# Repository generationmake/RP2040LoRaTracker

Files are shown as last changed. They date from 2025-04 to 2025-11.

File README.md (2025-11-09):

# RP2040LoRaTracker
Tracker with a Raspberry Pi RP2040, an AI-Thinker Ra-01 LoRa Module and an u-Blox GNSS receiver

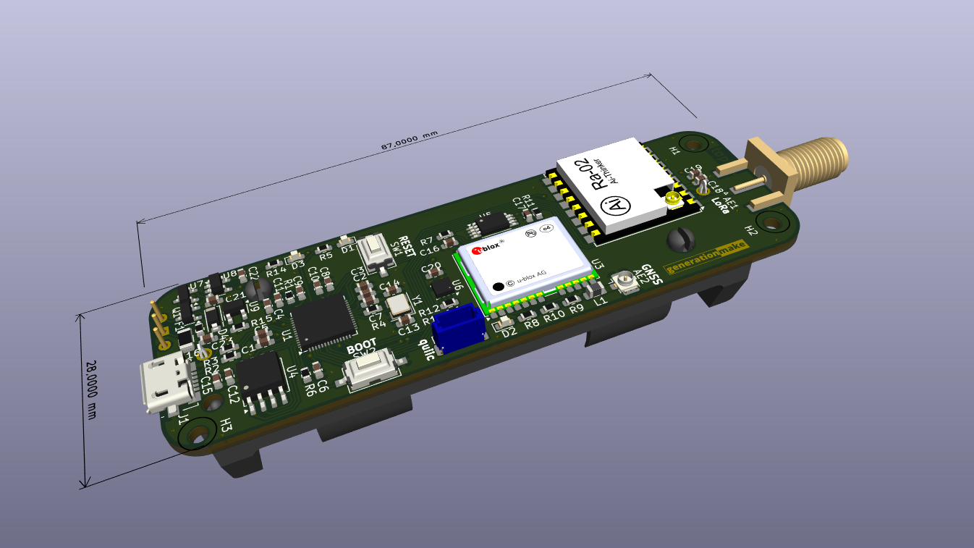
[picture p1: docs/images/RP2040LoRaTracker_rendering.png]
RP2040LoRaTracker rendering


## Firmware
* [ArduinoLoRaAPRSTracker](https://github.com/generationmake/ArduinoLoRaAPRSTracker): This is the default firmware for this board. It enables all basic functions as a ham radio LoRaAPRSTracker

## Antennas

### LoRa antenna (AE1)

SMA connector, 50 Ohm, for 433 MHz LoRa antenna.

### GNSS antenna (AE2)

U.FL connector, 50 Ohm, for GNSS antenna.

## Pinout

### USB (J1)

Micro-USB connector, connected to the RP2040 ant to charge the battery.

### I2C (J2)

compatible to the Sparkfun qwiic standard (https://www.sparkfun.com/qwiic). JST SH 1mm 4-pin.

| pin number | signal |
|:---:|:---:|
| 1 | GND |
| 2 | +3V3 |
| 3 | I2C_SDA |
| 4 | I2C_SCL |

## Switches

### Reset (SW1)

push button to reset RP2040.

### Boot (SW2)

push button to set RP2040 to boot mode.

### on/off (SW3)

sliding switch to power board from battery.

## enclosure

There exists a 3D printable enclosure to encapsulate the PCB.

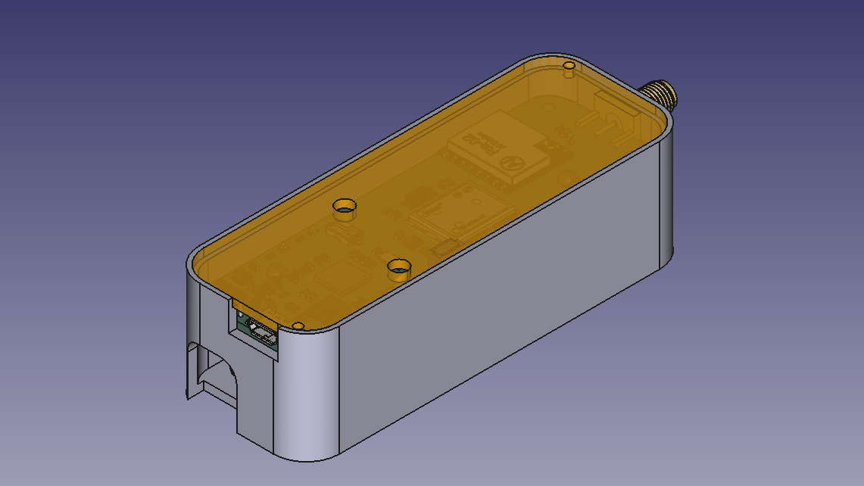
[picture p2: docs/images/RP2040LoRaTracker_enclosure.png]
RP2040LoRaTracker enclosure


## PCB

### Top

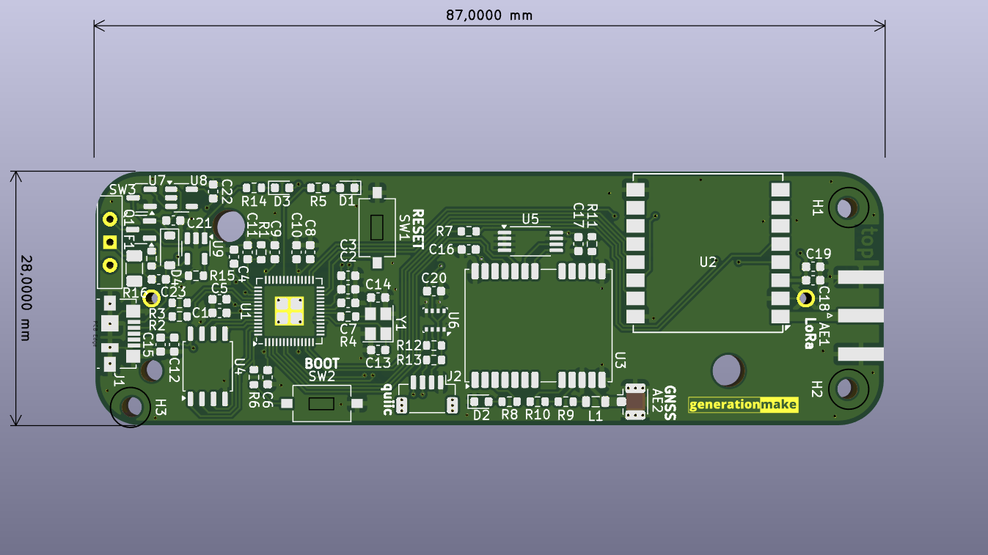
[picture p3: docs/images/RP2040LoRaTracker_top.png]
RP2040LoRaTracker PCB top


### Bottom

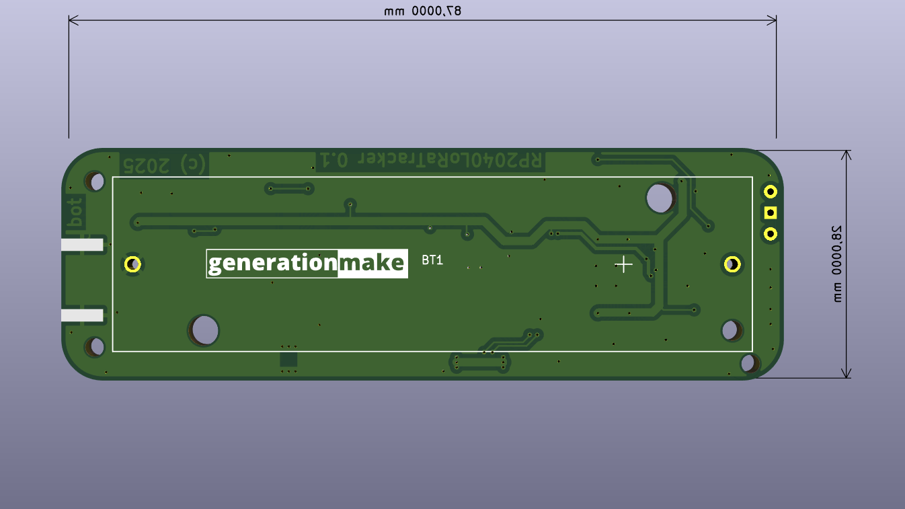
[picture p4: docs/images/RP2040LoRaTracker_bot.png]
RP2040LoRaTracker PCB bot


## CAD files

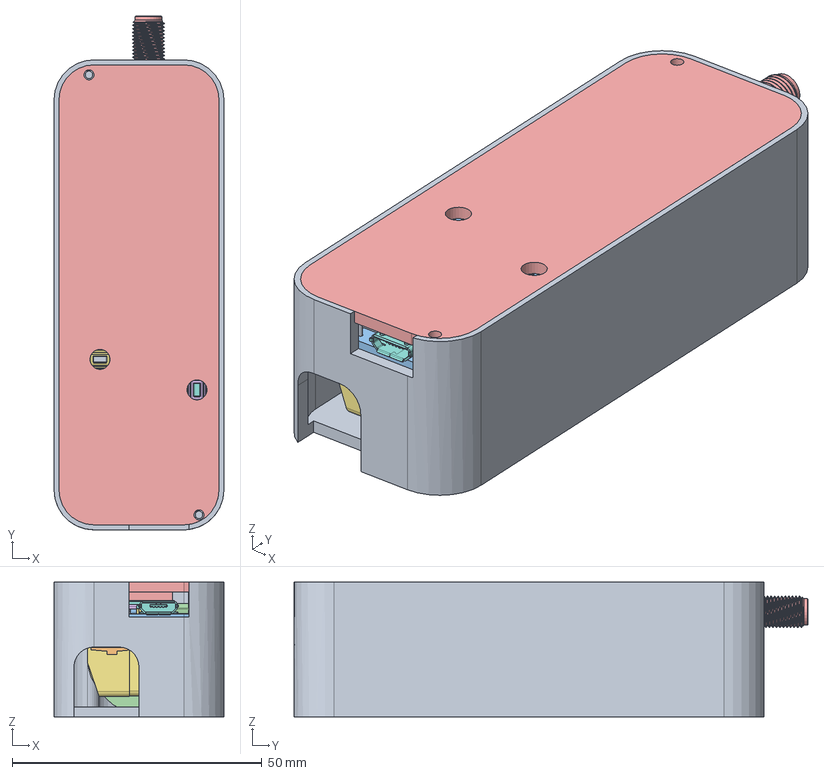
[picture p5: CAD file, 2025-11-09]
freecad_source/enclosure.FCStd
34.0 x 102.7 x 27.0 mm
bot
LED_0603_1608Metric
R_0603_1608Metric
R_0603_1608Metric002
NEO (STEP-AP214)_B
NEO (STEP-AP214)_B001
NEO (STEP-AP214)_B002
NEO (STEP-AP214)_B003
NEO (STEP-AP214)_B004
NEO (STEP-AP214)_B005
NEO (STEP-AP214)_B006
NEO (STEP-AP214)_B007
NEO (STEP-AP214)_B008
NEO (STEP-AP214)_B009
NEO (STEP-AP214)_B010
NEO (STEP-AP214)_B011
NEO (STEP-AP214)_B012
NEO (STEP-AP214)_B013
NEO (STEP-AP214)_B014
NEO (STEP-AP214)_B015
NEO (STEP-AP214)_B016
NEO (STEP-AP214)_B017
NEO (STEP-AP214)_B018
NEO (STEP-AP214)_B019
NEO (STEP-AP214)_B020
NEO (STEP-AP214)_B021
NEO (STEP-AP214)_B022
NEO (STEP-AP214)_B023
NEO (STEP-AP214)_B024
NEO (STEP-AP214)_B025
NEO (STEP-AP214)_B026
NEO (STEP-AP214)_B027
NEO (STEP-AP214)_B028
NEO (STEP-AP214)_B029
NEO (STEP-AP214)_B030
NEO (STEP-AP214)_B031
NEO (STEP-AP214)_B032
L_0805_2012Metric
C_0603_1608Metric
R_0603_1608Metric004
C_0603_1608Metric002
C_0603_1608Metric004
C_0603_1608Metric006
R_0603_1608Metric006
R_0603_1608Metric008
SOT_23
SOT_23_5
C_0603_1608Metric008
Fuse_1206_3216Metric
root
root001
root002
root003
root004
root005
root006
root007
root008
root009
root010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

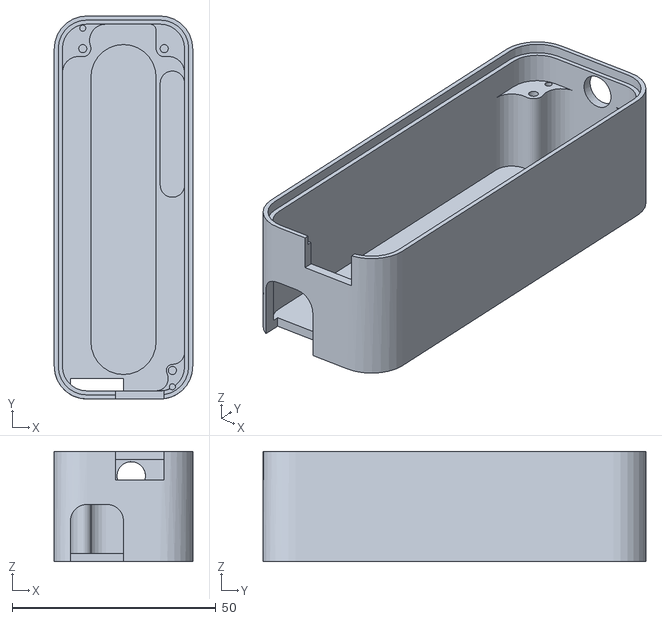
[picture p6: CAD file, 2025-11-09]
production_data/enclosure-bot.stl
34.0 x 94.0 x 27.0

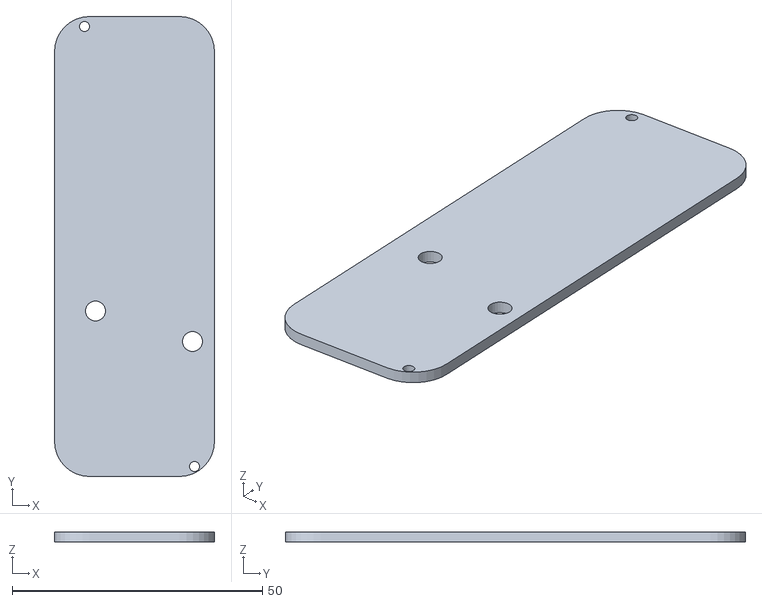
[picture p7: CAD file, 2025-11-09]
production_data/enclosure-top.stl
32.0 x 92.0 x 2.00

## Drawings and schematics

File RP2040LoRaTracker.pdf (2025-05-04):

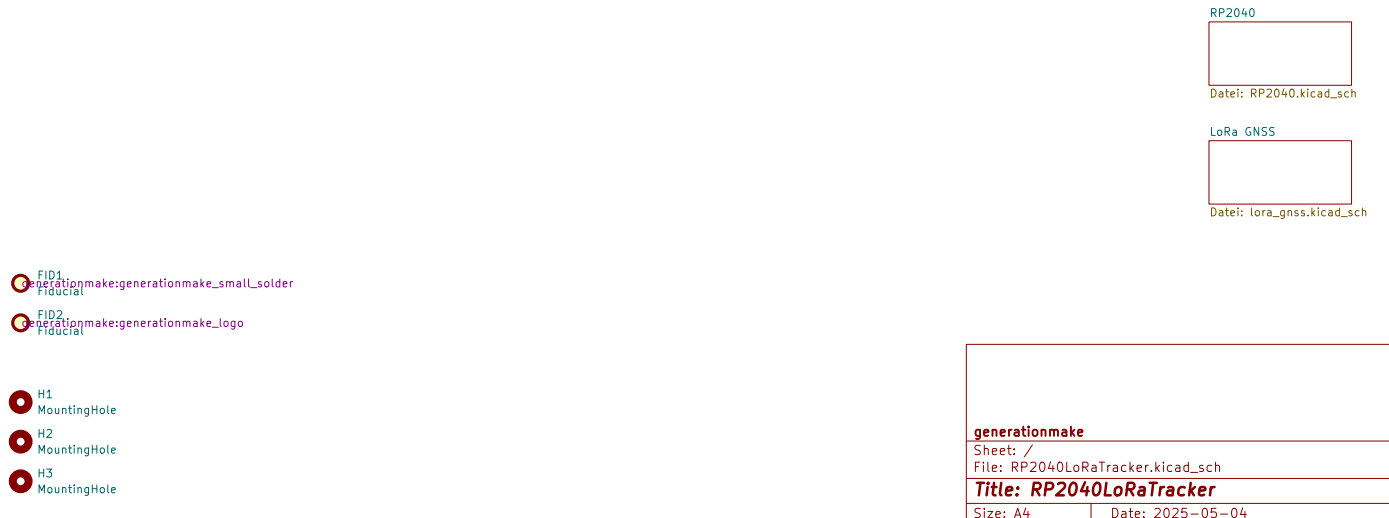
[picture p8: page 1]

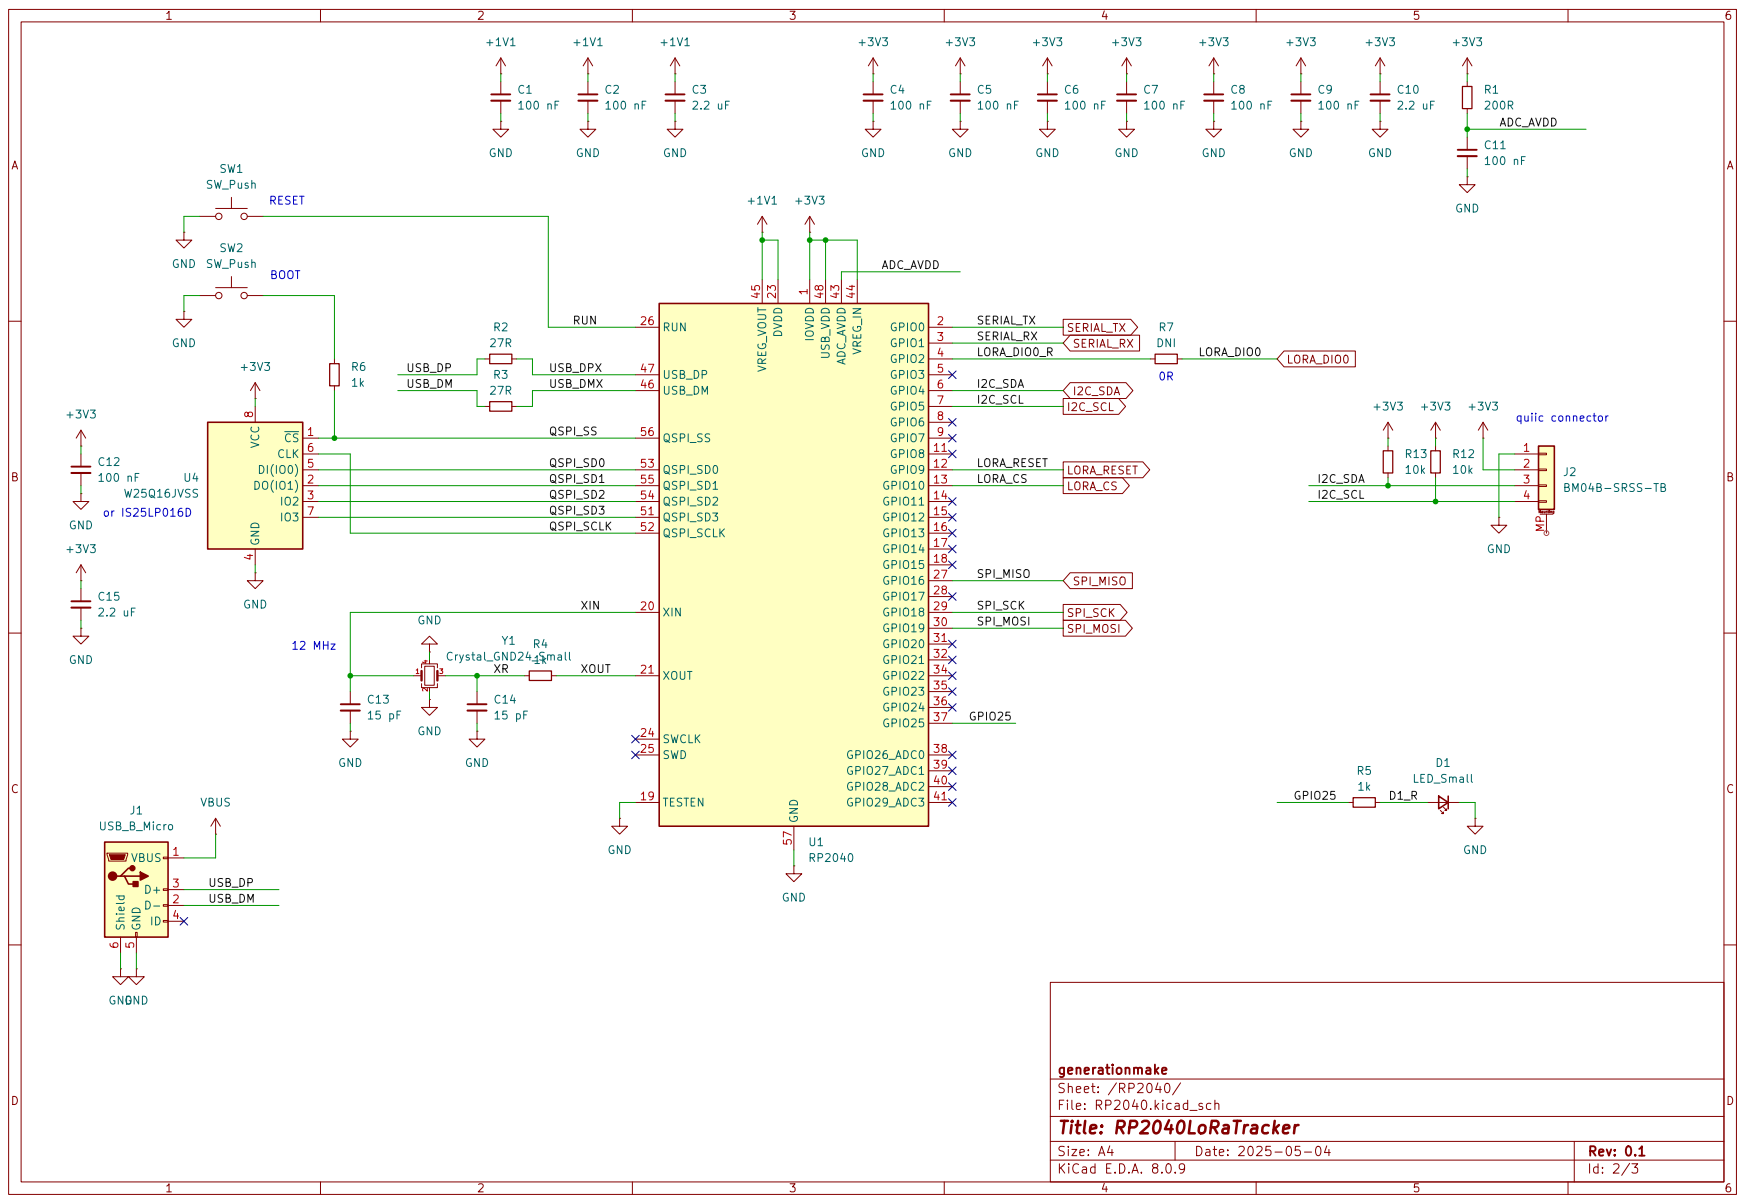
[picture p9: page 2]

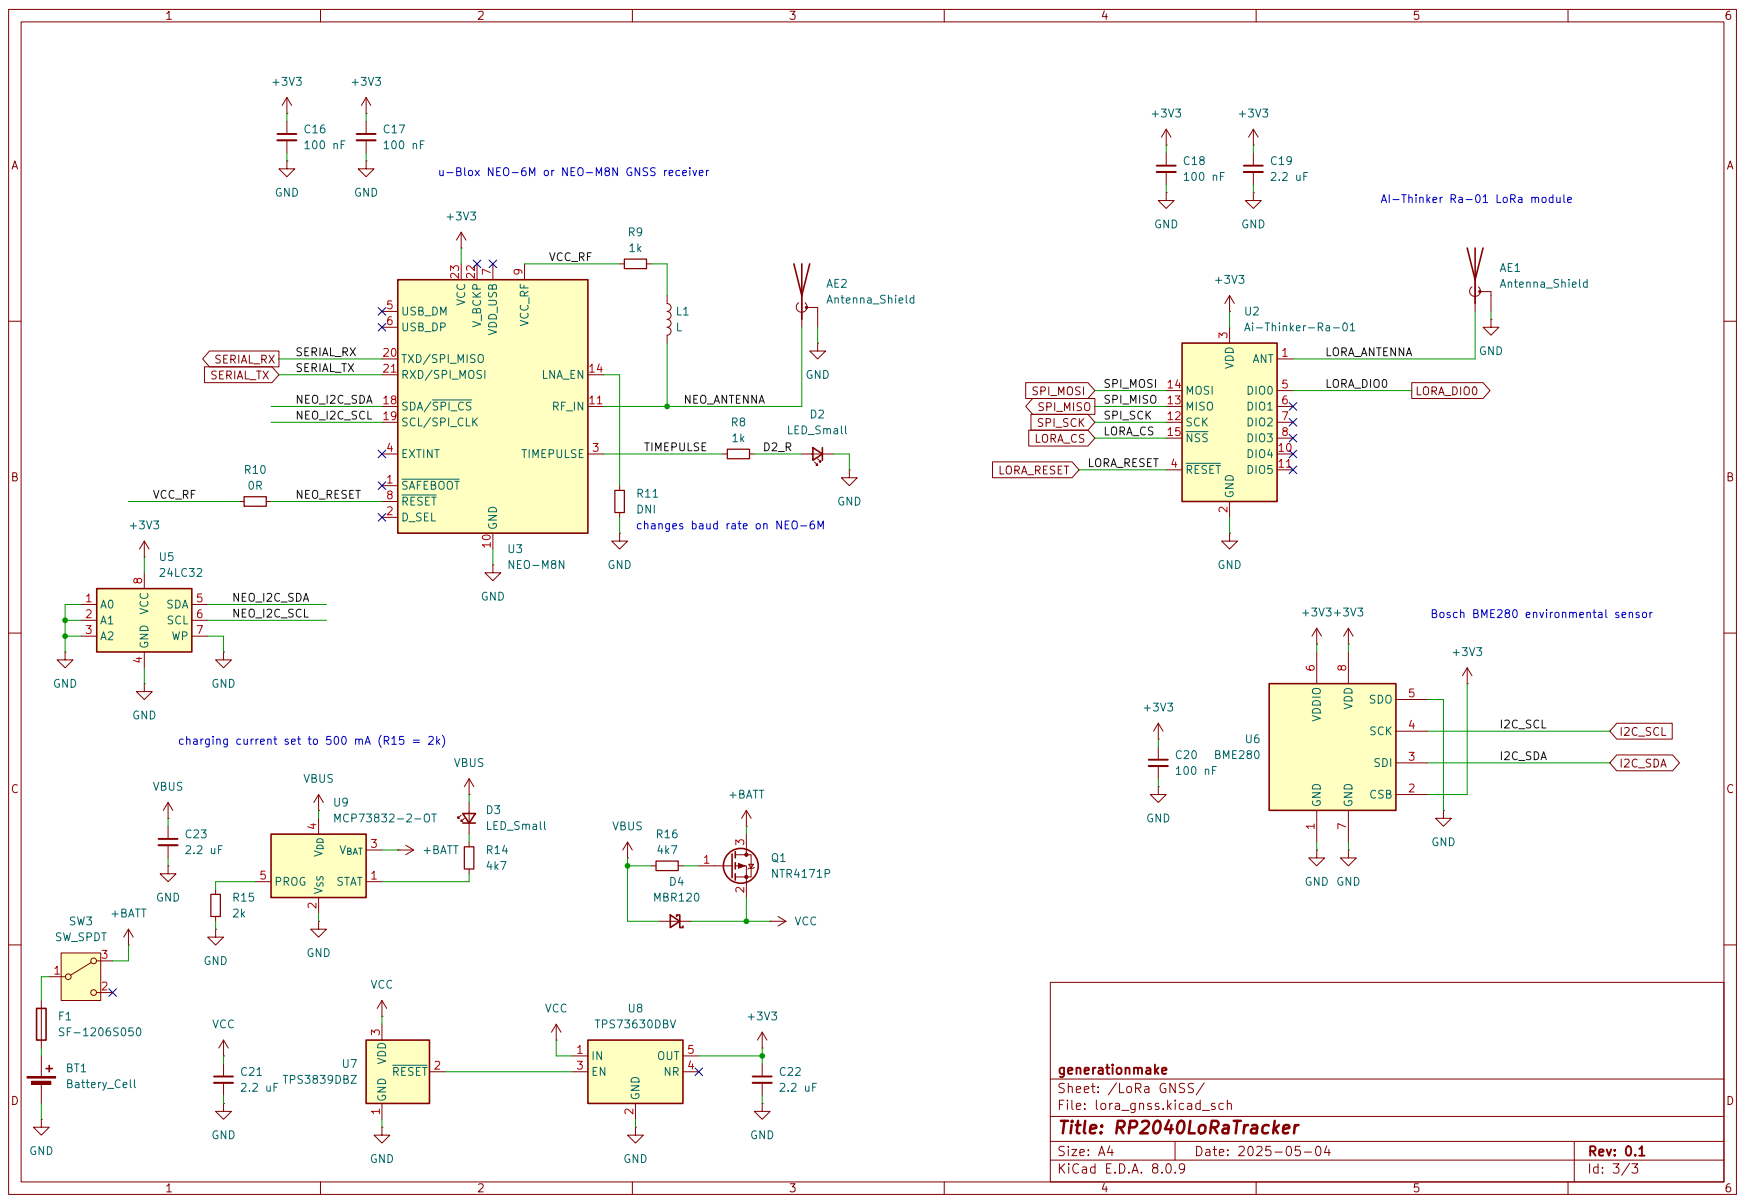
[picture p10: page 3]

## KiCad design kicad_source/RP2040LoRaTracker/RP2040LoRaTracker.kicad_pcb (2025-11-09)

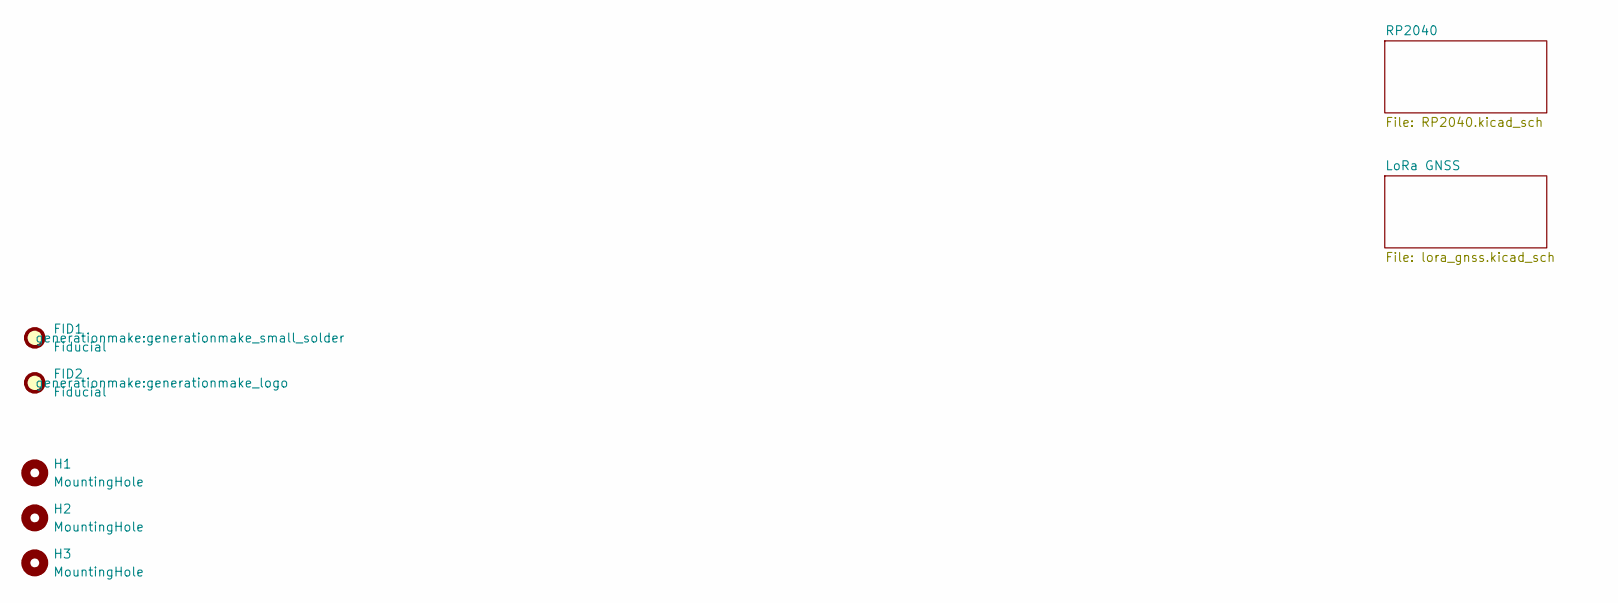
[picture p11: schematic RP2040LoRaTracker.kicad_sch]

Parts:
FID1: Fiducial; generationmake_small_solder
FID2: Fiducial; generationmake_logo
H1, H2, H3: MountingHole; MountingHole_2.2mm_M2

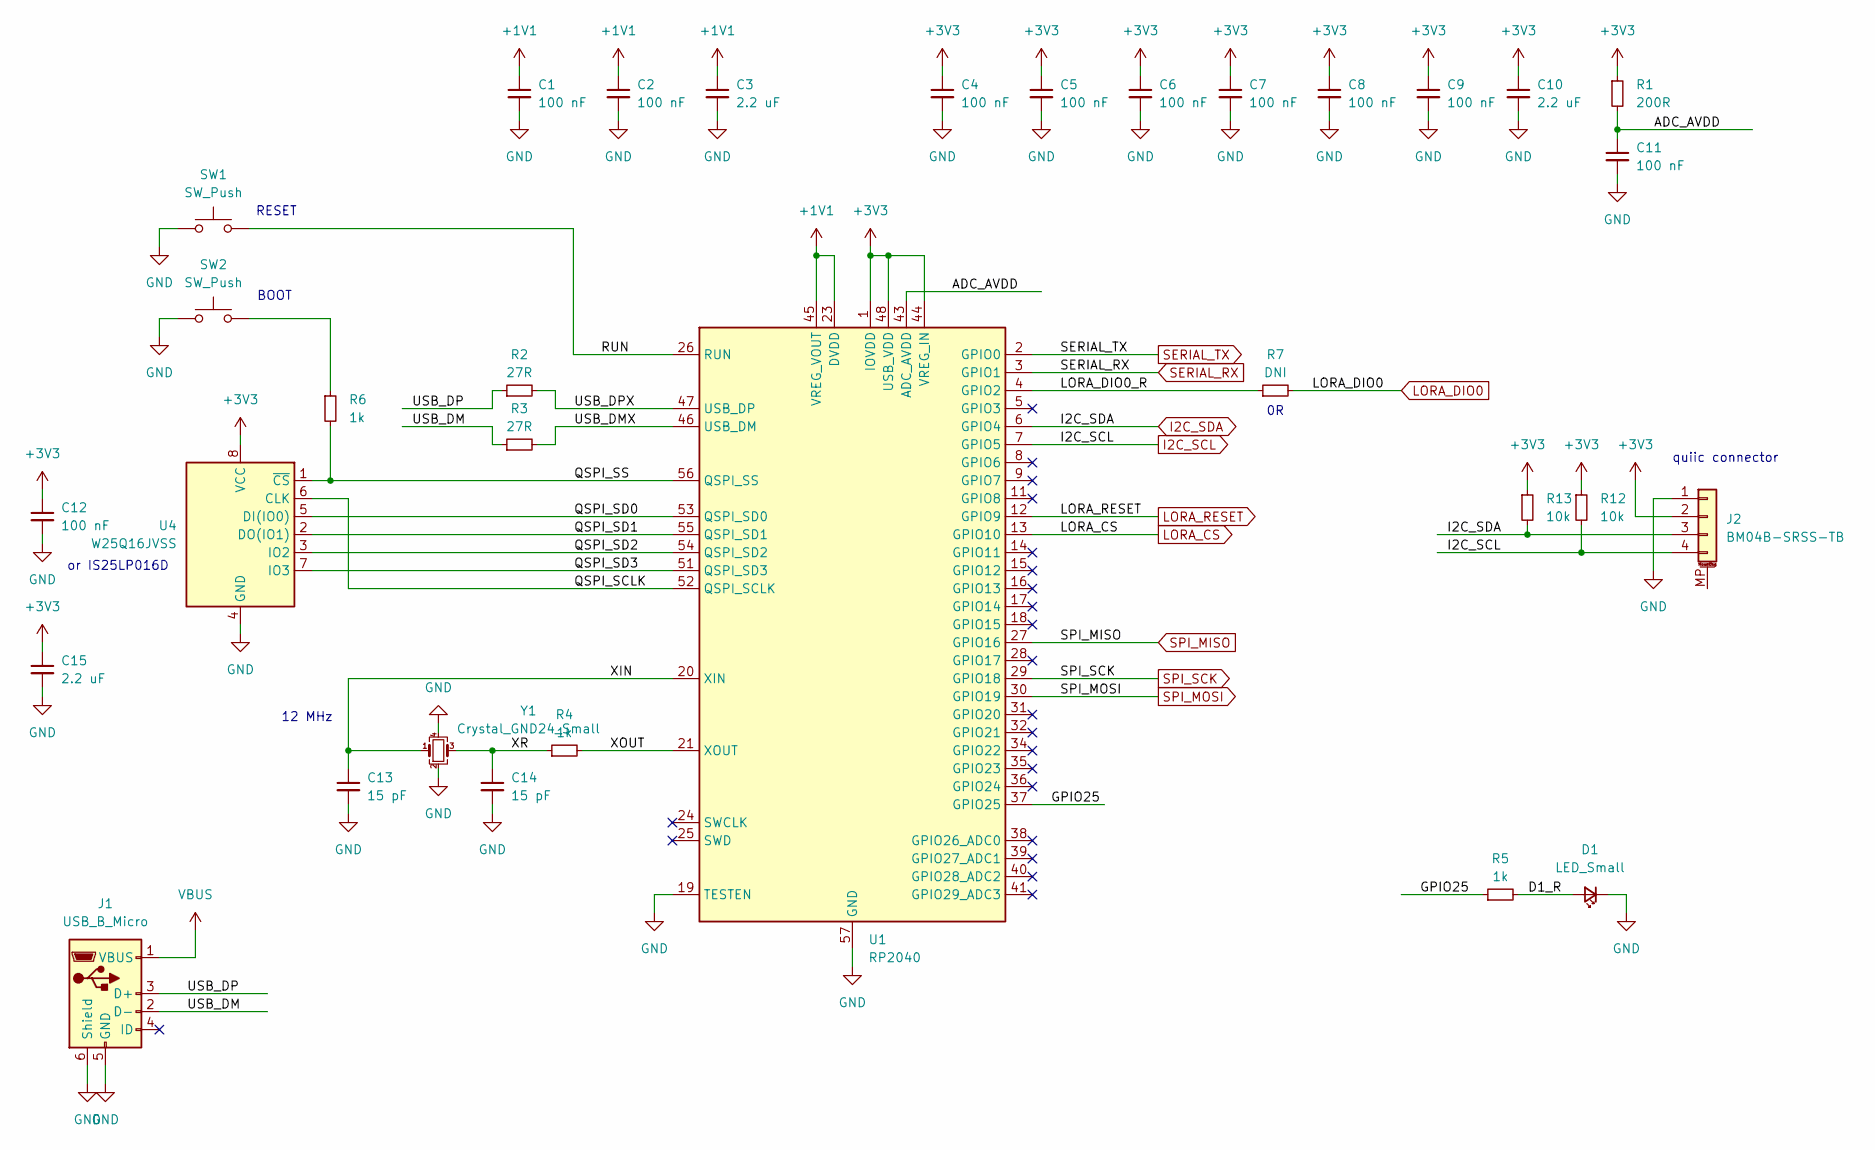
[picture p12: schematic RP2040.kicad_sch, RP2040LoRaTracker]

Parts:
C1, C2, C4, C5, C6, C7, C8, C9, C11, C12: 100 nF; C_0603_1608Metric
C3, C10, C15: 2.2 uF; C_0603_1608Metric
C13, C14: 15 pF; C_0603_1608Metric
D1: LED_Small; LED_0603_1608Metric
J1: USB_B_Micro; USB_Micro-B_Molex_47346-0001
J2: BM04B-SRSS-TB; JST_SH_BM04B-SRSS-TB_1x04-1MP_P1.00mm_Vertical
R1: 200R; R_0603_1608Metric
R2, R3: 27R; R_0603_1608Metric
R4, R5, R6: 1k; R_0603_1608Metric
R7: DNI; R_0603_1608Metric
R12, R13: 10k; R_0603_1608Metric
SW1, SW2: SW_Push; SW_Tactile_SPST_NO_Straight_CK_PTS636Sx25SMTRLFS
U1: RP2040; QFN-56-1EP_7x7mm_P0.4mm_EP3.2x3.2mm
U4: W25Q16JVSS; SOIC-8_5.275x5.275mm_P1.27mm
Y1: Crystal_GND24_Small; Crystal_SMD_3225-4Pin_3.2x2.5mm

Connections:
+1V1: C1.1, C2.1, C3.1, U1.23 (DVDD), U1.45 (VREG_VOUT), U1.50 (DVDD)
+3V3: C4.1, C5.1, C6.1, C7.1, C8.1, C9.1, C10.1, C12.1, C15.1, J2.2, R1.1, R12.1, R13.1, U1.1 (IOVDD), U1.10 (IOVDD), U1.22 (IOVDD), U1.33 (IOVDD), U1.42 (IOVDD), U1.44 (VREG_IN), U1.48 (USB_VDD), U1.49 (IOVDD), U4.8 (VCC); also elsewhere on the board
/RP2040/ADC_AVDD: C11.1, R1.2, U1.43 (ADC_AVDD)
/RP2040/D1_R: D1.2 (A), R5.2
/RP2040/GPIO25: R5.1, U1.37 (GPIO25)
/RP2040/LORA_DIO0_R: R7.1, U1.4 (GPIO2)
/RP2040/QSPI_SCLK: U1.52 (QSPI_SCLK), U4.6 (CLK)
/RP2040/QSPI_SD0: U1.53 (QSPI_SD0), U4.5 (DI(IO0))
/RP2040/QSPI_SD1: U1.55 (QSPI_SD1), U4.2 (DO(IO1))
/RP2040/QSPI_SD2: U1.54 (QSPI_SD2), U4.3 (IO2)
/RP2040/QSPI_SD3: U1.51 (QSPI_SD3), U4.7 (IO3)
/RP2040/QSPI_SS: R6.2, U1.56 (QSPI_SS), U4.1 (~CS)
/RP2040/RUN: SW1.2, U1.26 (RUN)
/RP2040/USB_DM: J1.2 (D-), R3.1
/RP2040/USB_DMX: R3.2, U1.46 (USB_DM)
/RP2040/USB_DP: J1.3 (D+), R2.1
/RP2040/USB_DPX: R2.2, U1.47 (USB_DP)
/RP2040/XIN: C13.1, U1.20 (XIN), Y1.1
/RP2040/XOUT: R4.2, U1.21 (XOUT)
/RP2040/XR: C14.1, R4.1, Y1.3
GND: C1.2, C2.2, C3.2, C4.2, C5.2, C6.2, C7.2, C8.2, C9.2, C10.2, C11.2, C12.2, C13.2, C14.2, C15.2, D1.1 (K), J1.5 (GND), J1.6 (Shield), J2.1, SW1.1, SW2.1, U1.19 (TESTEN), U1.57 (GND), U4.4 (GND), Y1.2, Y1.4; also elsewhere on the board
I2C_SCL: J2.4, R12.2, U1.7 (GPIO5); also elsewhere on the board
I2C_SDA: J2.3, R13.2, U1.6 (GPIO4); also elsewhere on the board
LORA_CS: U1.13 (GPIO10); also elsewhere on the board
LORA_DIO0: R7.2; also elsewhere on the board
LORA_RESET: U1.12 (GPIO9); also elsewhere on the board
unnamed: R6.1, SW2.2
SERIAL_RX: U1.3 (GPIO1); also elsewhere on the board
SERIAL_TX: U1.2 (GPIO0); also elsewhere on the board
SPI_MISO: U1.27 (GPIO16); also elsewhere on the board
SPI_MOSI: U1.30 (GPIO19); also elsewhere on the board
SPI_SCK: U1.29 (GPIO18); also elsewhere on the board
VBUS: J1.1 (VBUS); also elsewhere on the board

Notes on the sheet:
12 MHz
or IS25LP016D
quiic connector
BOOT
RESET

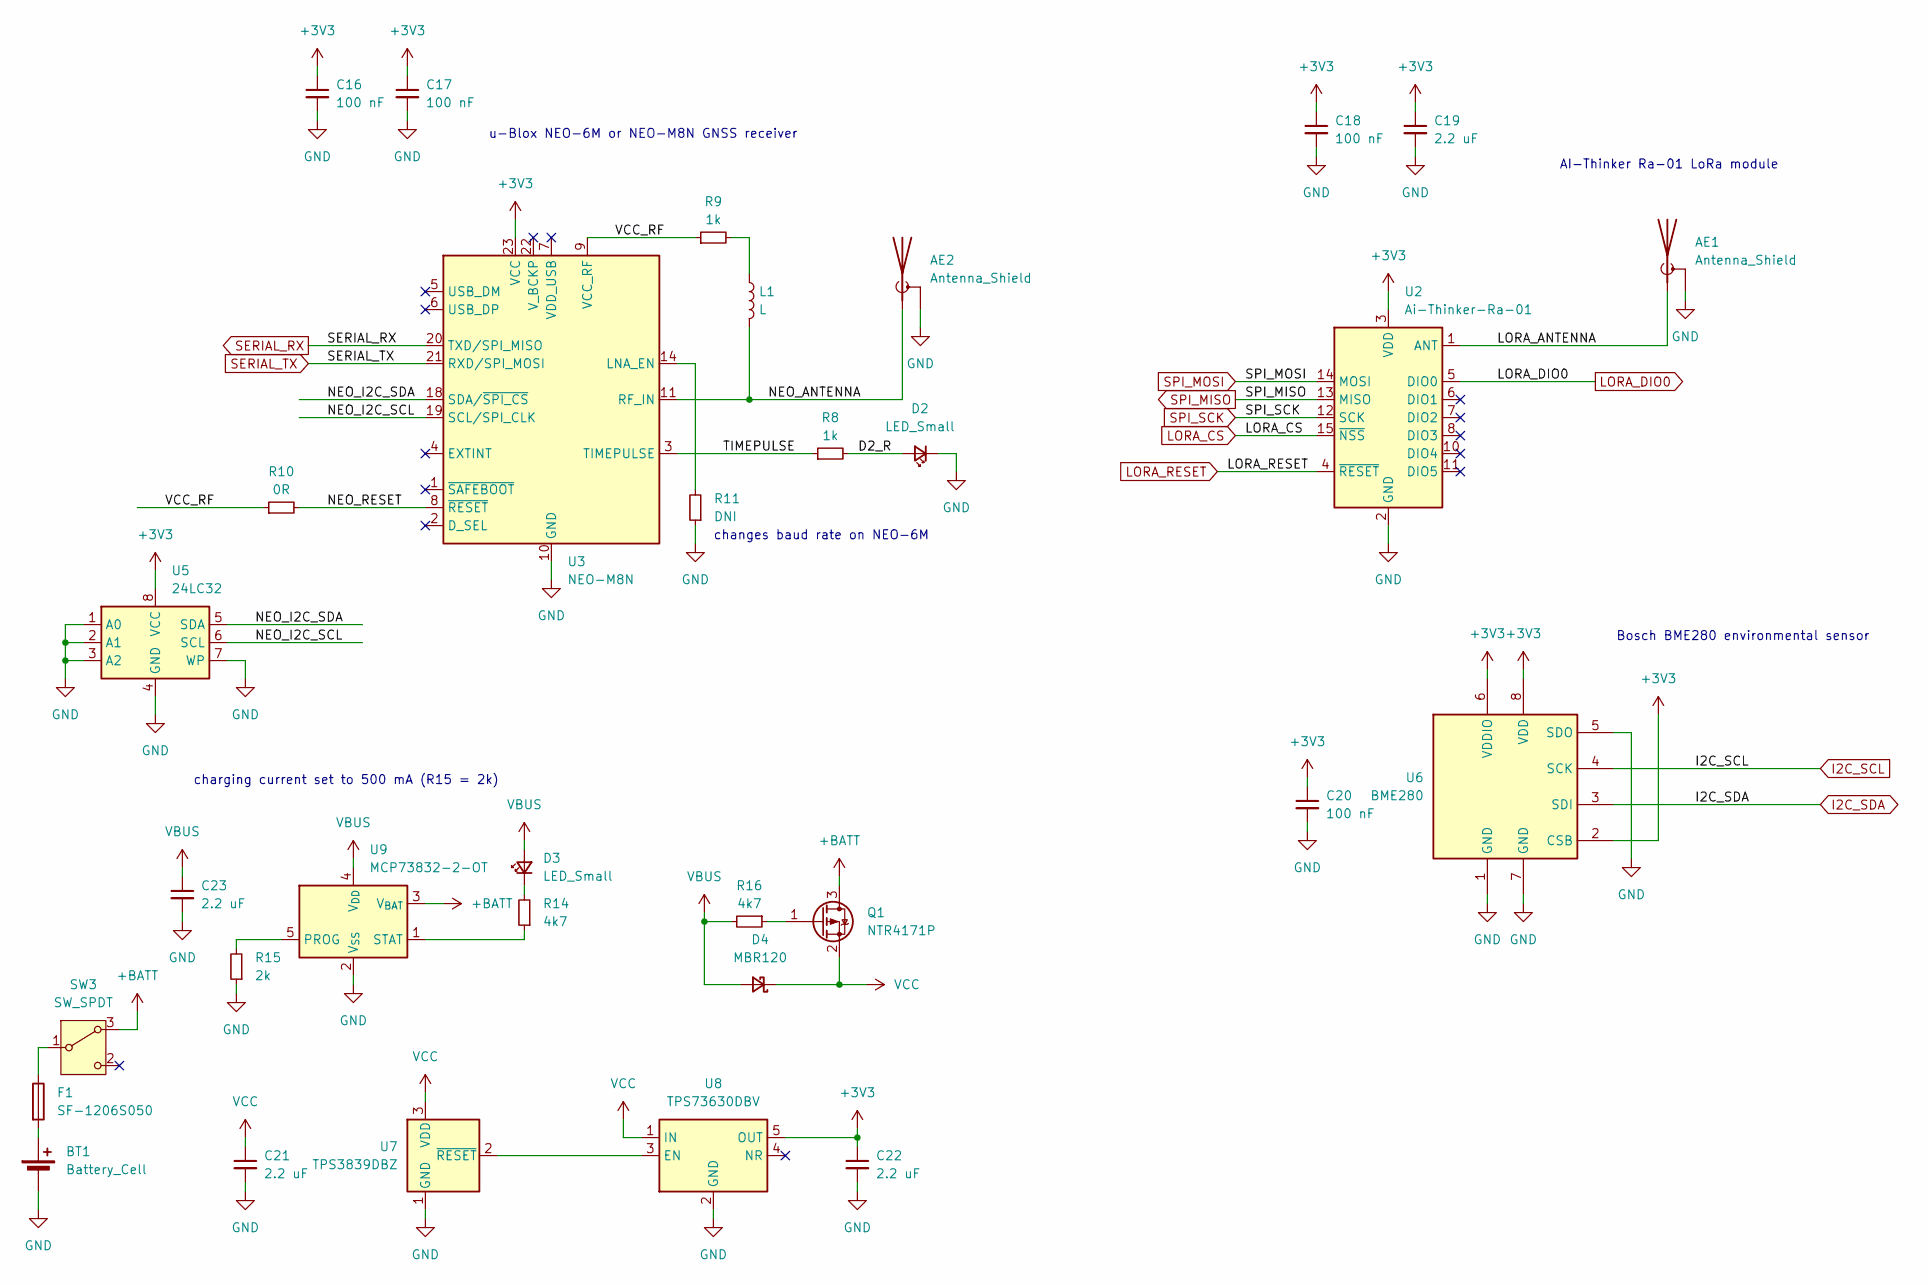
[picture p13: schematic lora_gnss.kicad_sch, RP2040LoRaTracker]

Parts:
AE1: Antenna_Shield; SMA_Amphenol_132289_EdgeMount
AE2: Antenna_Shield; U.FL_Hirose_U.FL-R-SMT-1_Vertical
BT1: Battery_Cell; KEYSTONE_1043
C16, C17, C18, C20: 100 nF; C_0603_1608Metric
C19, C21, C22, C23: 2.2 uF; C_0603_1608Metric
D2, D3: LED_Small; LED_0603_1608Metric
D4: MBR120; D_SOD-123
F1: SF-1206S050; Fuse_1206_3216Metric
L1: L; L_0805_2012Metric
Q1: NTR4171P; SOT-23
R8, R9: 1k; R_0603_1608Metric
R10: 0R; R_0603_1608Metric
R11: DNI; R_0603_1608Metric
R14, R16: 4k7; R_0603_1608Metric
R15: 2k; R_0603_1608Metric
SW3: SW_SPDT; SW_Slide-03_Wuerth-WS-SLTV_10x2.5x6.4_P2.54mm
U2: Ai-Thinker-Ra-01; Ai-Thinker-Ra-01-LoRa
U3: NEO-M8N; ublox_NEO
U5: 24LC32; TSSOP-8_4.4x3mm_P0.65mm
U6: BME280; Bosch_LGA-8_2.5x2.5mm_P0.65mm_ClockwisePinNumbering
U7: TPS3839DBZ; SOT-23
U8: TPS73630DBV; SOT-23-5
U9: MCP73832-2-OT; SOT-23-5

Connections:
+3V3: C16.1, C17.1, C18.1, C19.1, C20.1, C22.1, U2.3 (VDD), U3.23 (VCC), U5.8 (VCC), U6.2 (CSB), U6.6 (VDDIO), U6.8 (VDD), U8.5 (OUT); also elsewhere on the board
+BATT: Q1.3 (D), SW3.3 (A), U9.3 (V_{BAT})
/LoRa GNSS/D2_R: D2.2 (A), R8.2
/LoRa GNSS/LORA_ANTENNA: AE1.1 (A), U2.1 (ANT)
/LoRa GNSS/NEO_ANTENNA: AE2.1 (A), L1.2, U3.11 (RF_IN)
/LoRa GNSS/NEO_I2C_SCL: U3.19 (SCL/SPI_CLK), U5.6 (SCL)
/LoRa GNSS/NEO_I2C_SDA: U3.18 (SDA/~SPI_CS), U5.5 (SDA)
/LoRa GNSS/NEO_RESET: R10.2, U3.8 (~RESET)
/LoRa GNSS/TIMEPULSE: R8.1, U3.3 (TIMEPULSE)
/LoRa GNSS/VCC_RF: R9.1, R10.1, U3.9 (VCC_RF)
GND: AE1.2 (Shield), AE2.2 (Shield), BT1.2 (-), C16.2, C17.2, C18.2, C19.2, C20.2, C21.2, C22.2, C23.2, D2.1 (K), R11.1, R15.1, U2.2 (GND), U2.9 (GND), U2.16 (GND), U3.10 (GND), U3.12 (GND), U3.13 (GND), U3.24 (GND), U5.1 (A0), U5.2 (A1), U5.3 (A2), U5.4 (GND), U5.7 (WP), U6.1 (GND), U6.5 (SDO), U6.7 (GND), U7.1 (GND), U8.2 (GND), U9.2 (V_{SS}); also elsewhere on the board
I2C_SCL: U6.4 (SCK); also elsewhere on the board
I2C_SDA: U6.3 (SDI); also elsewhere on the board
LORA_CS: U2.15 (~NSS); also elsewhere on the board
LORA_DIO0: U2.5 (DIO0); also elsewhere on the board
LORA_RESET: U2.4 (~RESET); also elsewhere on the board
unnamed: BT1.1 (+), F1.2
unnamed: D3.1 (K), R14.2
unnamed: L1.1, R9.2
unnamed: Q1.1 (G), R16.1
unnamed: F1.1, SW3.1 (B)
unnamed: R11.2, U3.14 (LNA_EN)
unnamed: U7.2 (~RESET), U8.3 (EN)
unnamed: R15.2, U9.5 (PROG)
unnamed: R14.1, U9.1 (STAT)
SERIAL_RX: U3.20 (TXD/SPI_MISO); also elsewhere on the board
SERIAL_TX: U3.21 (RXD/SPI_MOSI); also elsewhere on the board
SPI_MISO: U2.13 (MISO); also elsewhere on the board
SPI_MOSI: U2.14 (MOSI); also elsewhere on the board
SPI_SCK: U2.12 (SCK); also elsewhere on the board
VBUS: C23.1, D3.2 (A), D4.2 (A), R16.2, U9.4 (V_{DD}); also elsewhere on the board
VCC: C21.1, D4.1 (K), Q1.2 (S), U7.3 (VDD), U8.1 (IN)

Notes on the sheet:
changes baud rate on NEO-6M
u-Blox NEO-6M or NEO-M8N GNSS receiver
charging current set to 500 mA (R15 = 2k)
Bosch BME280 environmental sensor
AI-Thinker Ra-01 LoRa module

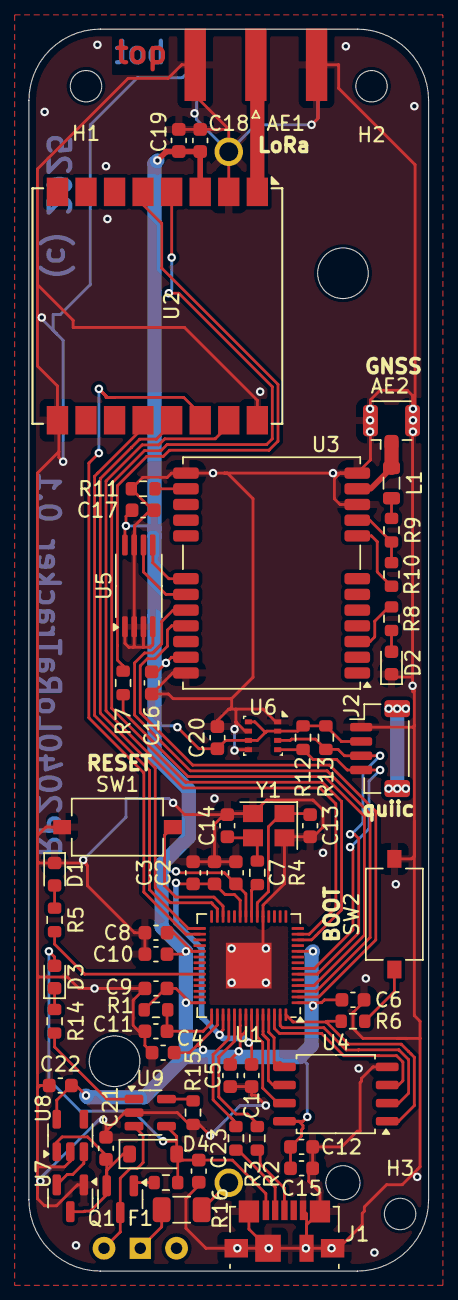
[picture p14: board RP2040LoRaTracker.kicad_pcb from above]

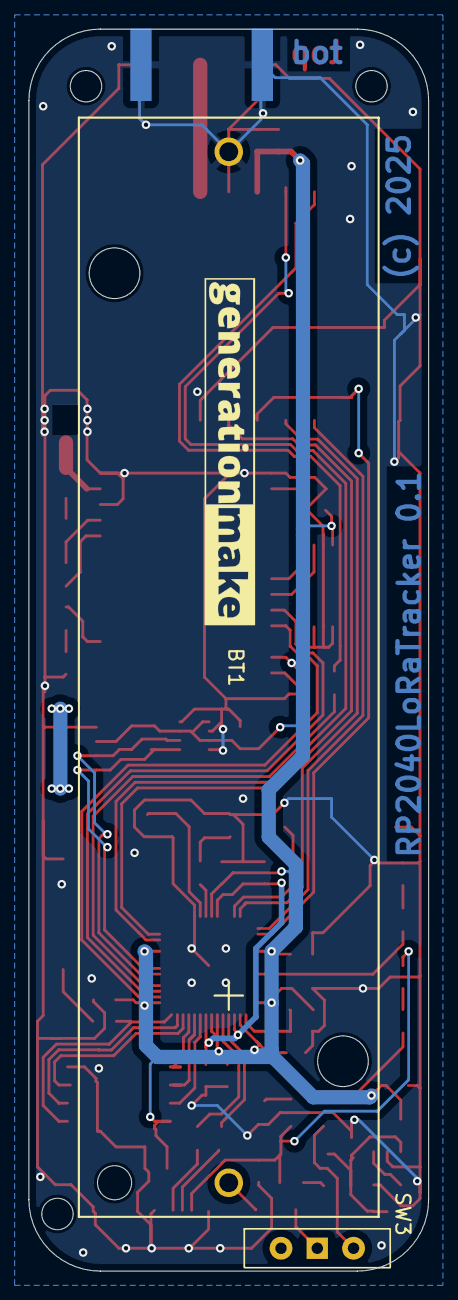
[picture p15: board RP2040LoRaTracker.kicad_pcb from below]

Board: 2 copper layers, 28.0 x 87.0 mm, 69 parts (3 on the bottom side), 52 nets.

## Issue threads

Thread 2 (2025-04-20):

improvements for rev. 0.2

generationmake, 2025-04-20:
* add backup battery for GNSS
  * change footprint of USB connector
  * change to 14500 main battery
  * embed GNSS antenna

generationmake, 2025-04-22:
measurement of input or battery voltage

generationmake, 2025-04-22:
dual layout for Ra-01 and RFM98W???

generationmake, 2025-09-13:
> dual layout for Ra-01 and RFM98W???

nope

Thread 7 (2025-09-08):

enclosure

generationmake, 2025-09-08:
generate and correct step file
generate 3D printable enclosure

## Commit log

2025-03-31 started schematic
    [RP2040.kicad_sch, RP2040LoRaTracker.kicad_pcb, RP2040LoRaTracker.kicad_sch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]
2025-03-31 started layout
    [RP2040.kicad_sch, RP2040LoRaTracker.kicad_pcb, lora_gnss.kicad_sch]
2025-03-31 added BME280 and quiic connector
    [RP2040.kicad_sch, RP2040LoRaTracker.kicad_pcb, lora_gnss.kicad_sch]
2025-03-31 added voltage regulator
    [RP2040LoRaTracker.kicad_pcb, lora_gnss.kicad_sch]
2025-03-31 added battery charger
    [RP2040.kicad_sch, RP2040LoRaTracker.kicad_pcb, lora_gnss.kicad_sch]
2025-03-31 added schematic pdf
2025-03-31 changed battery holder, updated layout
    [RP2040LoRaTracker.kicad_pcb, lora_gnss.kicad_sch]
2025-04-01 beautified layout, made DRC
    [RP2040.kicad_sch, RP2040LoRaTracker.kicad_pcb, RP2040LoRaTracker.kicad_sch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]
2025-04-20 updated some values in schematic, added comments, updated schematic pdf
    [RP2040.kicad_sch, RP2040LoRaTracker.kicad_pcb, RP2040LoRaTracker.kicad_sch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]
2025-05-04 set charging current to 500 mA (R15=2k)
    [RP2040.kicad_sch, RP2040LoRaTracker.kicad_sch, lora_gnss.kicad_sch]
2025-09-09 updated some 3d models in footprints
    [RP2040LoRaTracker.kicad_pcb]
2025-09-09 fixed all 3d models in footprints
    [RP2040.kicad_sch, RP2040LoRaTracker.kicad_pcb, lora_gnss.kicad_sch]
2025-09-09 updated rendering
    [RP2040LoRaTracker.kicad_pcb]
2025-09-09 added freecad project
    [enclosure.FCStd]
2025-09-09 added enclosure, added top part
    [enclosure.FCStd]
2025-09-09 generated stl files
    [enclosure-bot.stl, enclosure-top.stl, enclosure.FCStd]

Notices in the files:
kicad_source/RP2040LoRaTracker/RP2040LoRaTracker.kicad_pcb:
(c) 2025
